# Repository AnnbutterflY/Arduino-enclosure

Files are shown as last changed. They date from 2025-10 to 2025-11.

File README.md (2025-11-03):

# 前言 Forward
本次课题是为Arduino设计外壳，制作要求为

This project involves designing a enclosure for Arduino, with the following requirements

**1、** 结合 3D 打印与激光切割技术

Combine 3D printing and laser cutting technologies

**2、** 禁止使用胶水，仅可使用螺丝或机械连接

The use of glue is prohibited; only screws or mechanical connections are allowed

**3、** 设计一个具有未来合理性的产品（Speculative Product），并为其制作外壳，推想该设计从构建一个可发生的未来开始。通过“未来世界”的设定，设计可以摆脱当下限制，探索替代思维

Design a speculative product with future plausibility and create a shell for it, imagining from the construction of a possible future. Through the setting of a "future world," design can break free from present constraints and explore alternative thinking

## 由此，我的世界构想为 Therefore, my world concept is:

**未来法律设定：** 所有家庭和公共空间不得使用一次性电子产品，所有硬件设备必须采用“可生长、可修复”的模块化设计，通过环境引导其功能发展。人们像培育植物一样“养”设备，而非简单购买固定功能的产品.

**社会形态与关键事件：** 地球经历工业体系崩塌和环境严重破坏的关键事件后，人类社会转向技术与生态共生的模式。社区不再依赖大型工厂生产日常设备，而是以家庭和社区为单位，通过“培养”技术植物满足生产和生活需求。社会形态呈现去中心化、生态化与模块化协作特征。

**整体环境与视觉风格：** 城市与废墟交融，建筑表面、屋顶、墙面遍布发光的电子藤蔓和生长的设备花朵。视觉风格融合科技与有机生物形态，光线柔和、呼吸式光源贯穿环境，半废墟、半生机的未来景观。

**生活方式、日常行为与核心需求:** 人们的生活不再围绕购买设备，而是通过培育和引导设备成长来满足生活需求。日常行为像照顾植物一样：调节光照、湿度和养分，引导设备长出不同功能模块。核心需求从“拥有设备”转向“培养、共生与管理设备成长”。

**Future Legal Framework:** All households and public spaces are prohibited from using disposable electronic products. All hardware devices must adopt a modular design that is “growable and repairable,” allowing their functions to develop through environmental guidance. People “nurture” devices like plants, rather than simply purchasing products with fixed functions.

**Societal Structure and Key Events:** Following critical events such as the collapse of industrial systems and severe environmental degradation, human society has shifted toward a model of technological-ecological symbiosis. Communities no longer rely on large factories to produce daily devices; instead, households and local communities “cultivate” technological plants to meet production and living needs. Society is characterized by decentralization, ecological integration, and modular collaboration.

**Overall Environment and Visual Style:** Cities blend with ruins, with building surfaces, rooftops, and walls covered in glowing electronic vines and blossoming devices. The visual style merges technology with organic, biological forms, featuring soft lighting and breathing light sources throughout the environment, creating a semi-ruined yet semi-vibrant futuristic landscape.

**Lifestyle, Daily Practices, and Core Needs:** Life is no longer centered on purchasing devices; instead, people nurture and guide devices’ growth to meet their needs. Daily actions resemble caring for plants: adjusting light, humidity, and nutrients to guide devices in growing different functional modules. Core needs have shifted from “owning devices” to “cultivating, coexisting with, and managing the growth of devices.”

# 反思 Reflection
在本次课题的制作过程中，我出现过问题。我制作的arduino外壳模型偏离了“HTAM”。

During the production process of this project, I encountered some problems. The Arduino case model I made deviated from the concept of “HTAM.”

我首先构思草图，然后用AI生图工具分别生成了华丽的底座与上半部分的成品2D图片。

I first sketched out my ideas, and then used an AI image-generation tool to create fantastic 2D images of an base and the upper part of the finished product.

<p align="center">
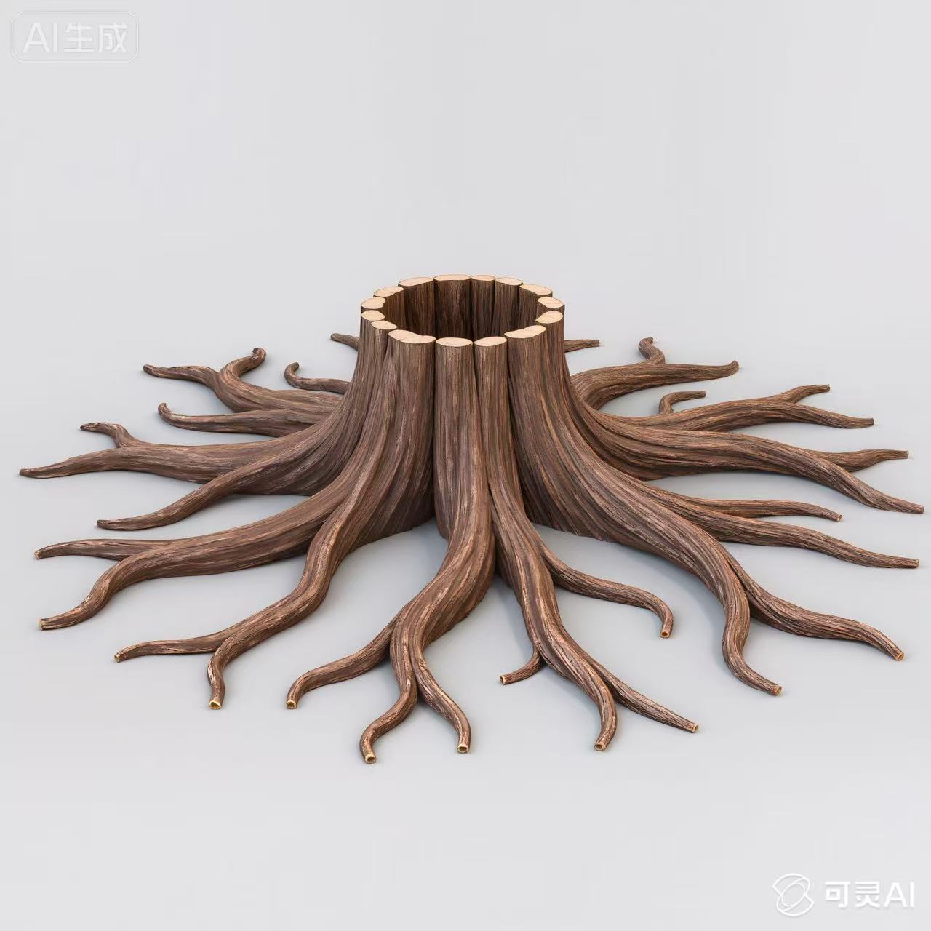
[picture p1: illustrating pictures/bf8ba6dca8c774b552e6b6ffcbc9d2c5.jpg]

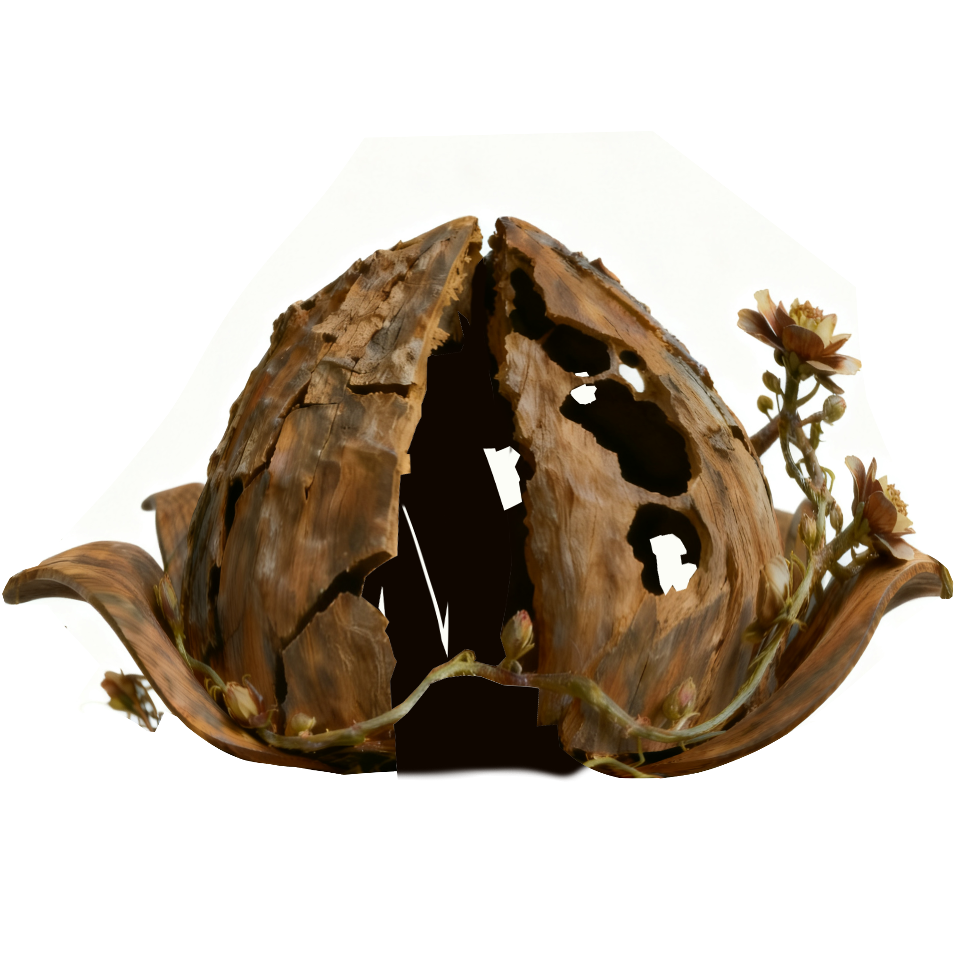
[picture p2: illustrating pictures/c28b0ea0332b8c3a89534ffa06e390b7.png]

</p>

接下来，我寻找到了AI生成模型网站：tripo3d（我的邀请码：E93EKF），我将图片上传，然后网站自动为我生成了模型。

Next, I found an AI model generation website called Tripo3D (my invitation code: E93EKF). I uploaded the images, and the site automatically generated 3D models for me.

<p align="center">
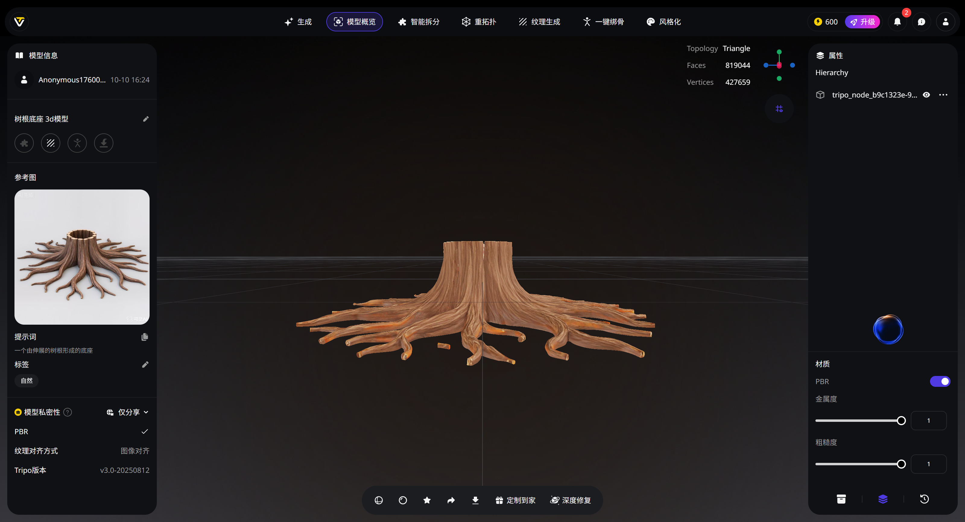
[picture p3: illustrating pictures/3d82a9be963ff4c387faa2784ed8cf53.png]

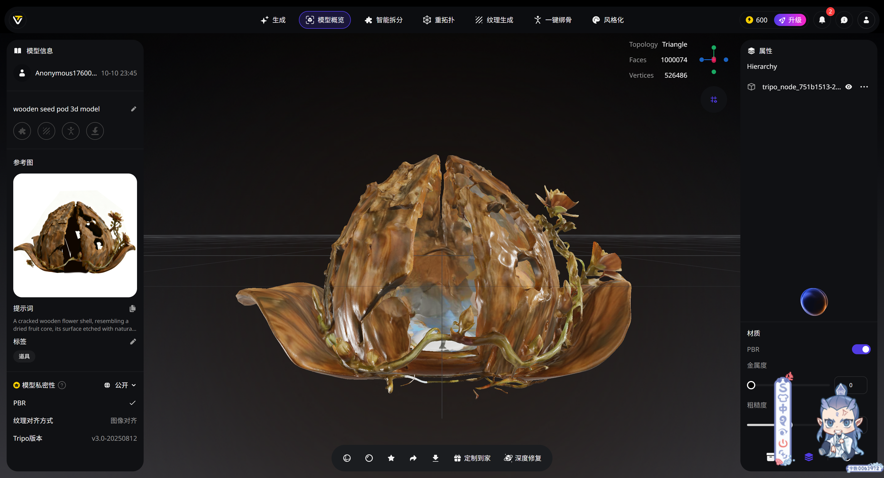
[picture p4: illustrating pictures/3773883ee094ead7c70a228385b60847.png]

</p>

于是，我将模型进行比例的修改，并进行破面修补、模型删减，并将底座与果壳结合在一起。

Then, I adjusted the proportions of the model, repaired broken surfaces, removed unnecessary parts, and combined the base with the shell.

最终，形成了一个类似火龙果的我的作品。

Eventually, my work took on the form of something resembling a dragon fruit.

<p align="center">
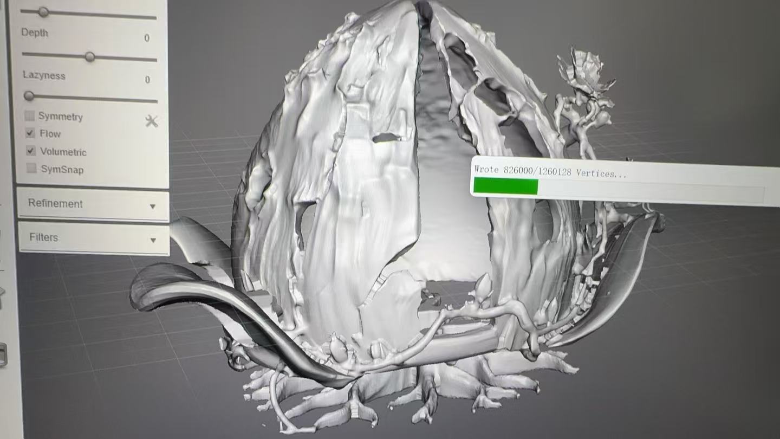
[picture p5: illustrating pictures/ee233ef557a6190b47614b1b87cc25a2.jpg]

</p>

然而，当我进入Fablab制作时，这一作品甚至难以被3D打印文件准备程序所预览，有无数需要支撑的部分，完全无法被制作、被生产。并且，我思考的将arduino放置于果壳内部的方式也不妥。更重要的是，这些设计完全没有必要。

However, when I brought the model to the Fablab for fabrication, it could barely even be previewed by the 3D printing preparation software—there were countless unsupported parts, making it completely impossible to produce.Furthermore, the way I planned to place the Arduino inside the shell was impractical. More importantly, these design decisions were entirely unnecessary.

<p align="center">
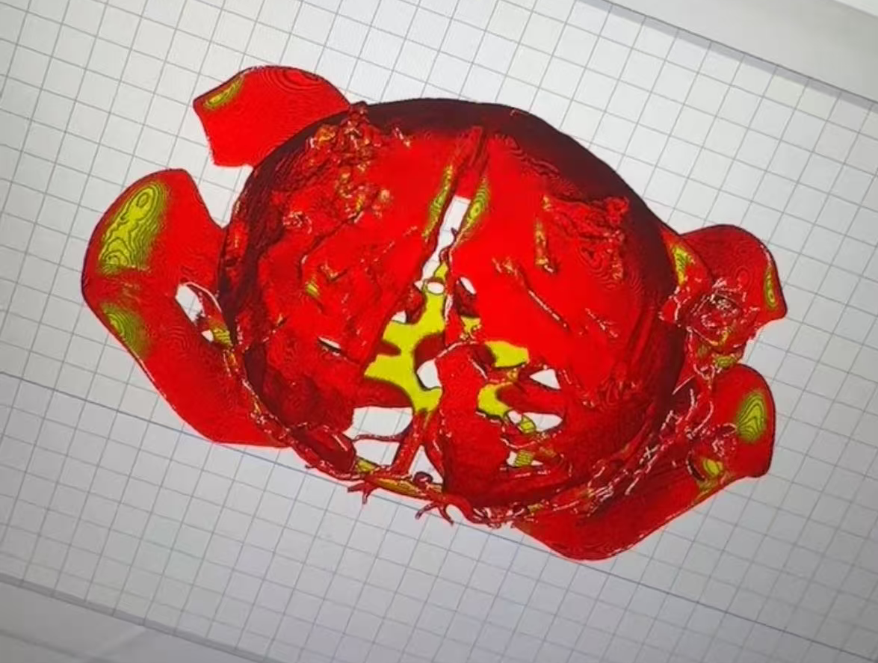
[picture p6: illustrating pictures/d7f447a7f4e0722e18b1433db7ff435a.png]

</p>

在这一过程中，我将它肆意捏造形状，而非关注于物体被激光切割和3D打印的制造方式，这导致我的外壳更像一个难以被制作的个人艺术装置，而不是未来的世界中的arduino外壳制作，完全脱离了制作目的。老师及时地提醒了我。在审课题时，我应该认真关注题目后的学会制造物品的意义。

Throughout this process, I focused on arbitrarily shaping forms rather than considering how the object would actually be made through laser cutting or 3D printing. As a result, my case looked more like a personal art installation that was nearly impossible to fabricate, rather than a practical Arduino case design for a futuristic world—it completely deviated from the purpose of making.Fortunately, my instructor reminded me in time. When reviewing the project, I realized I should focus more seriously on the meaning of learning to manufacture objects.

在经历这个过程后，我将模型重新拆分为上、下部分，将连接方式从不靠谱的打印件的捏造改为了结构穿插，并且修改了底座与外壳的形状，让他更符合未来arduino外壳的设计概念与我的未来世界规则，让他可被制造。

After going through this process, I split the model back into upper and lower parts, changed the unreliable printed connections into interlocking structural ones, and modified the base and shell shapes to better fit the design concept of a futuristic Arduino case and my envisioned world—making it manufacturable.

<p align="center">
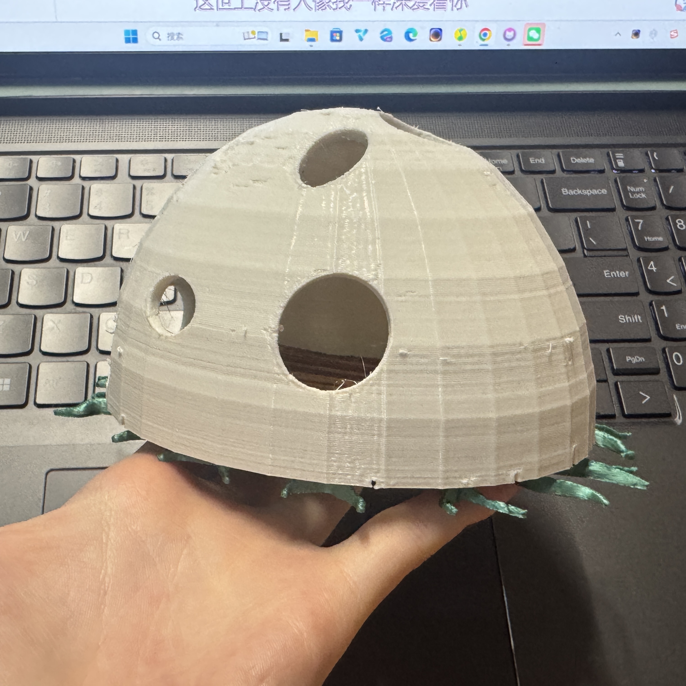
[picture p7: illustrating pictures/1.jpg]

</p>
<p align="center">  
改后制作完毕的样子
</p>  
<p align="center">  
The appearance after the revised version was completed.
</p>  

# tips:
我的教程中将会仅呈现如何制作出这样一个成品arduino外壳的完整过程，撇去了设计失败并迭代的过程。

In my tutorial, I will only present the complete process of how to make such a finished Arduino case, omitting the failed design attempts and iterations.

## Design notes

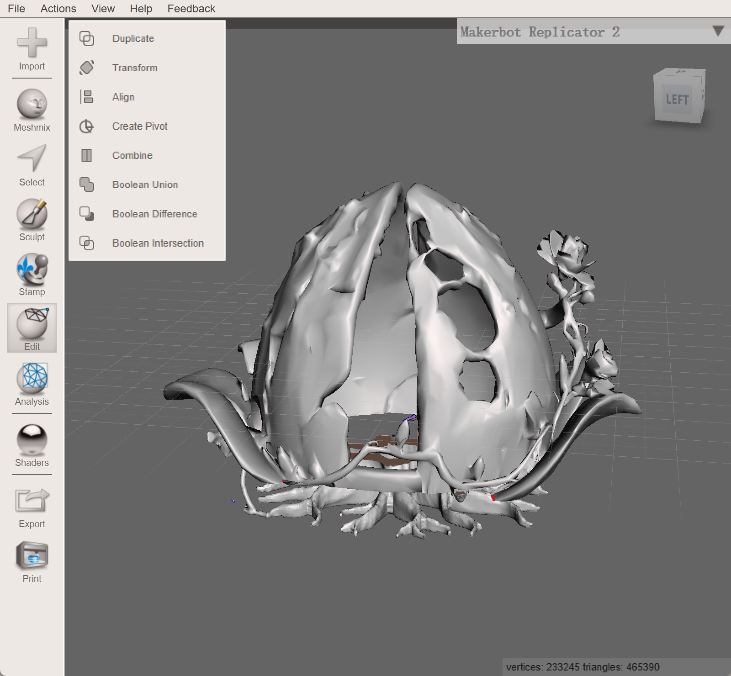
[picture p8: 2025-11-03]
illustrating pictures/e650ba2c14099867cfa3b52b1376ceb4.png

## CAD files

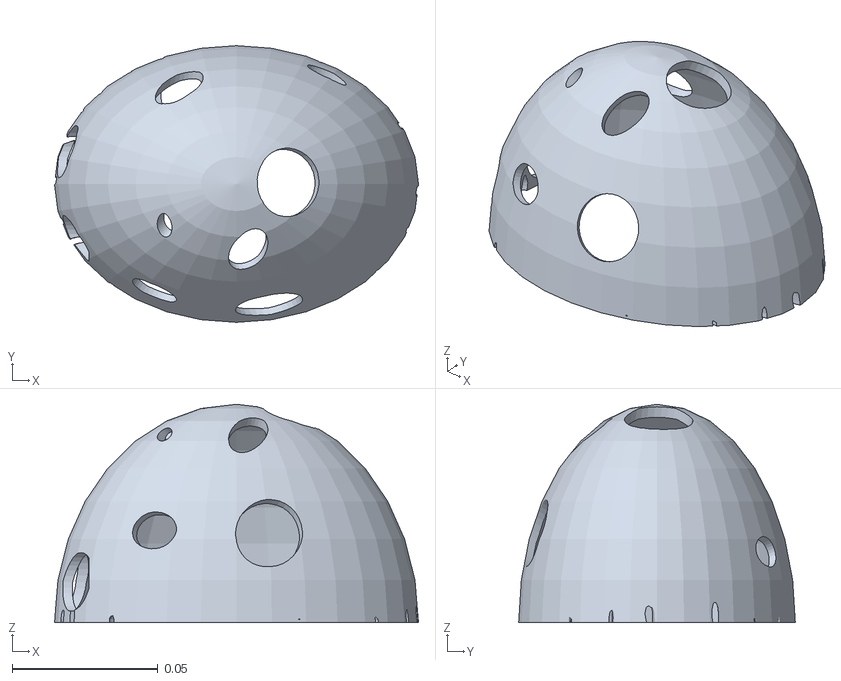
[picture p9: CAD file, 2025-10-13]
files/Shell (upper part).stl
0.125 x 0.095 x 0.075

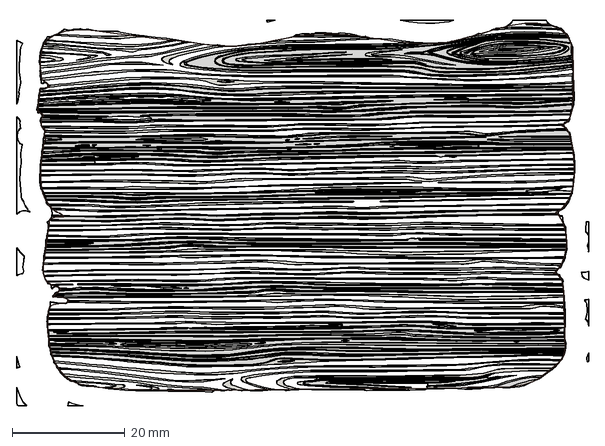
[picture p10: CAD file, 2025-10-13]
files/The wood board section for laser cutting.dxf
101.4 x 68.9 mm

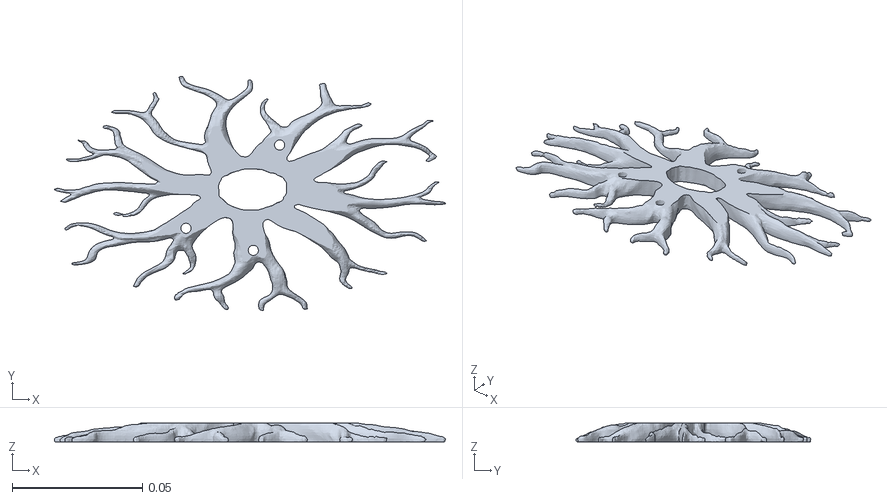
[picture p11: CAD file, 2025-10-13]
files/Base (lower part).stl
0.15 x 0.09 x 0.00716

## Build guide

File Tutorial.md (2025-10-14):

# 构思 Thinking  
在我的世界中，Arduino可根据周围环境的变化而**生长**，所以我名为**NURTSHELL**的外壳必须通透，留有余空，底座也要与环境共生，让Arduino被摆放在各个生长点上。  
In my envisioned world, the Arduino can **grow according to changes in its surroundings.** Therefore, my **NURTSHELL** must be transparent and spacious, and the base must coexist with the environment, allowing the Arduino to be placed at various growth points. I planned to use 3D printing to create a root-shaped base and a semi-enclosed shell, and laser cutting and engraving to build a wooden support inside.

# 木质支撑的制作 making the wooden support
## 第一步：制图  drawing
### 使用工具：AI  
**1、** 在官网（https://www.arduino.cc/ ）了解Arduino Uno R3的尺寸。  

Visit the official website (https://www.arduino.cc/) to learn the dimensions of the Arduino Uno R3.  
<p align="center">
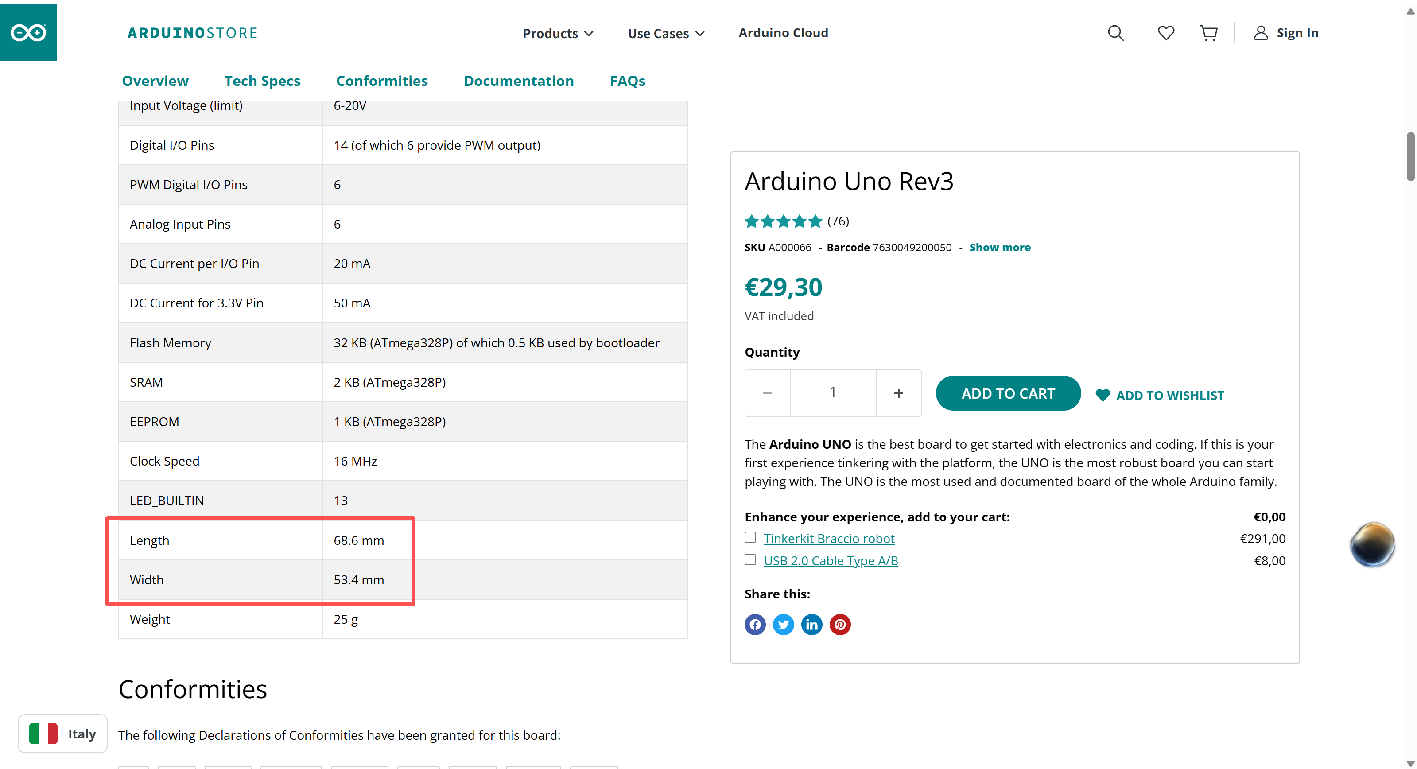
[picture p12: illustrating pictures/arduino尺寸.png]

</p>

**2、** 在AI中画出想要的木质支撑的切割形状，确保其能覆盖Arduino的大小。  

Draw the cutting shape of the wooden support in Illustrator (AI), ensuring it can cover the size of the Arduino.

**3、** 添加想要雕刻的纹路。  

Add the engraving patterns you desire.

<p align="center">
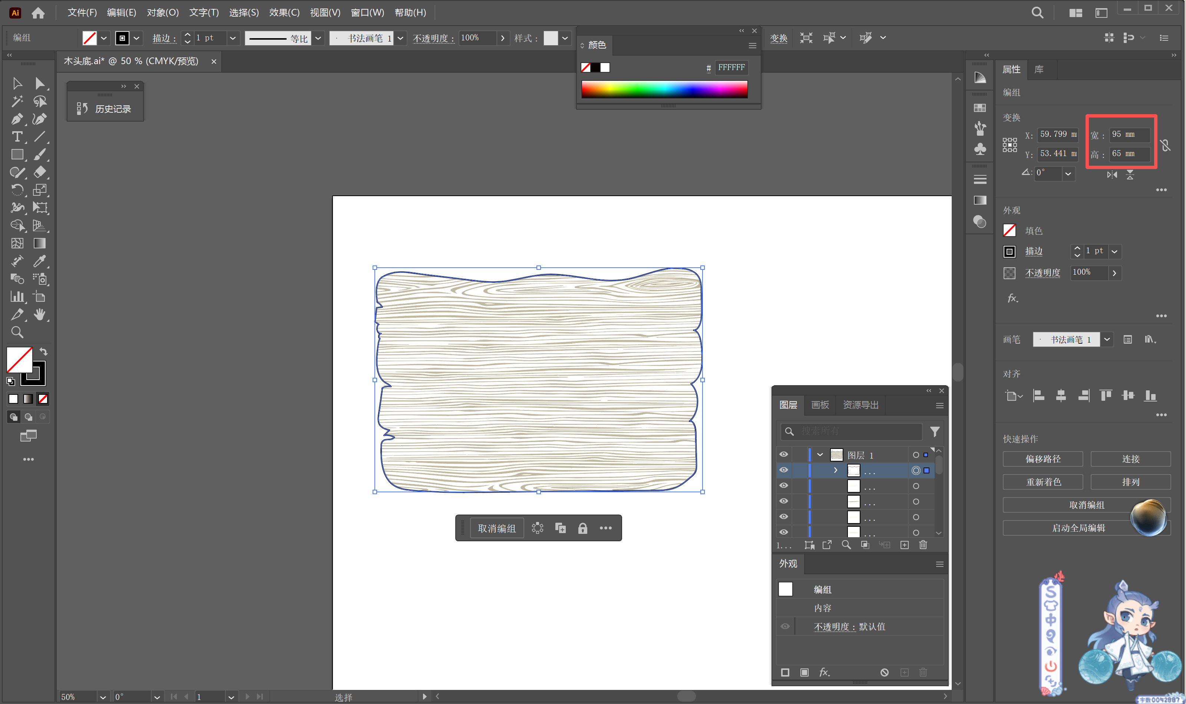
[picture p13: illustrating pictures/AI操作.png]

</p>
<p align="center">
我此处添加的雕刻纹路有些过于密集，打出来效果还可以，但尽量避免这么密集的线条。  
  
The engraving lines I added here were a bit too dense. Although the outcome was acceptable, it’s better to avoid such dense lines.
</p>

**4、** 留出需要与3D打印部分使用钉子连接固定的孔位。（我将使用直径为3.9mm的洞与其适配的热熔螺母、钉子）

**注意：** 此条需要重视，我就遗漏了这一步。 

Reserve holes for connecting with 3D-printed parts using screws. (I used 3.9 mm holes with matching heat-set inserts and screws.)  
 
**Note:** This step is crucial—I personally forgot it.

**5、** 将文件保存为**AI** 格式或**DXF**格式。  
 
 Save the file in **AI** or **DXF**format.

## 第二步：切割与雕刻  Cutting and Carving
### 使用工具：工坊一楼的激光切割机与一旁的电脑 The laser cutting machine on the first floor of the workshop and the computer next to it.

### 第一部分：电脑操作  
**1、** 在电脑上打开自己画好的图纸，打开方式选择LaserCAD。  

Open your design file on the computer using LaserCAD.

<p align="center">
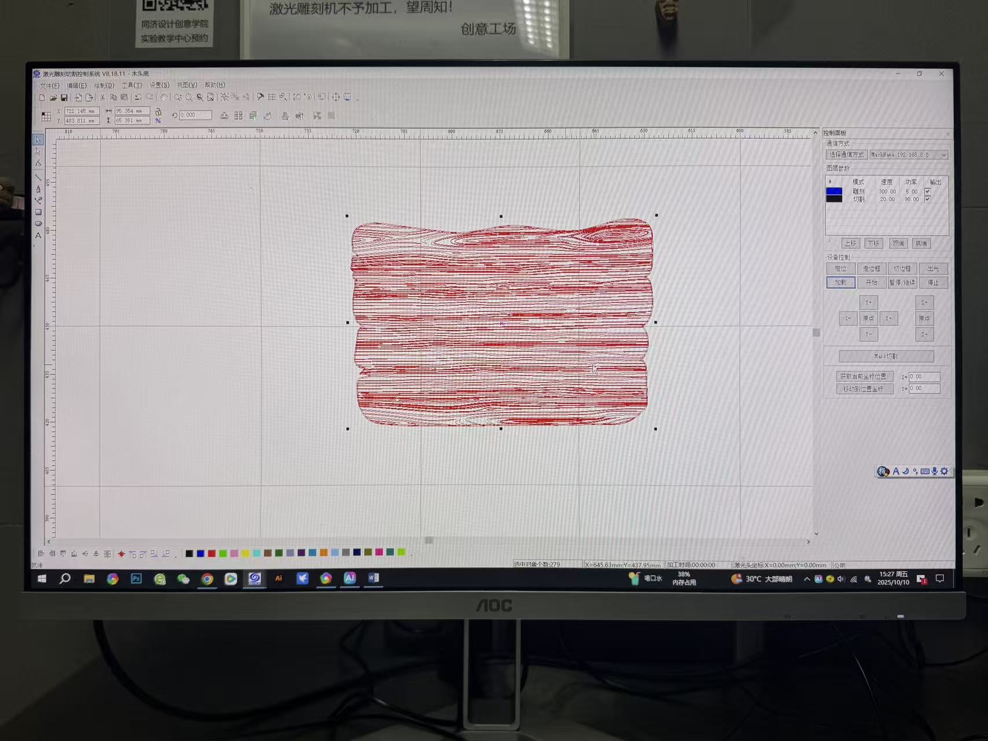
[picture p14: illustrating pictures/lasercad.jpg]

</p>

**2、** 观察图纸是否有乱线、图案是否完全显示。 

**提示：** 乱线删除即可，图案不显示很有可能是没有将文字、图形进行扩展。  

Check for stray lines or missing graphics.  

**Tip:** Delete stray lines; missing graphics are often caused by unexpanded text or shapes.

**3、** 全部选中线条，改为蓝色，需要切割的部分改为黑色。（剩下的蓝色部分为雕刻）  

原理：**不同颜色对应不同运行速度与功率，图层顺序先雕刻再切割。**  

Select all lines and set engraving lines to blue, cutting lines to black.  

Principle: **Different colors correspond to different speed and power settings. The machine engraves first, then cuts.**

<p align="center">
loading
</p>

**4、** 双击查看**右侧运行数值**，切割参数可参考电脑桌面“切割参数”PDF文件，雕刻参数可询问负责老师，3mm木板一般使用功率3-5，速度300。  

Double-click to view the **operation settings** on the right. Cutting parameters can be found in the “Cutting Parameters” PDF on the desktop; engraving parameters can be confirmed with the instructor. For 3mm wood, power 3–5 and speed 300 are typical.

<p align="center">
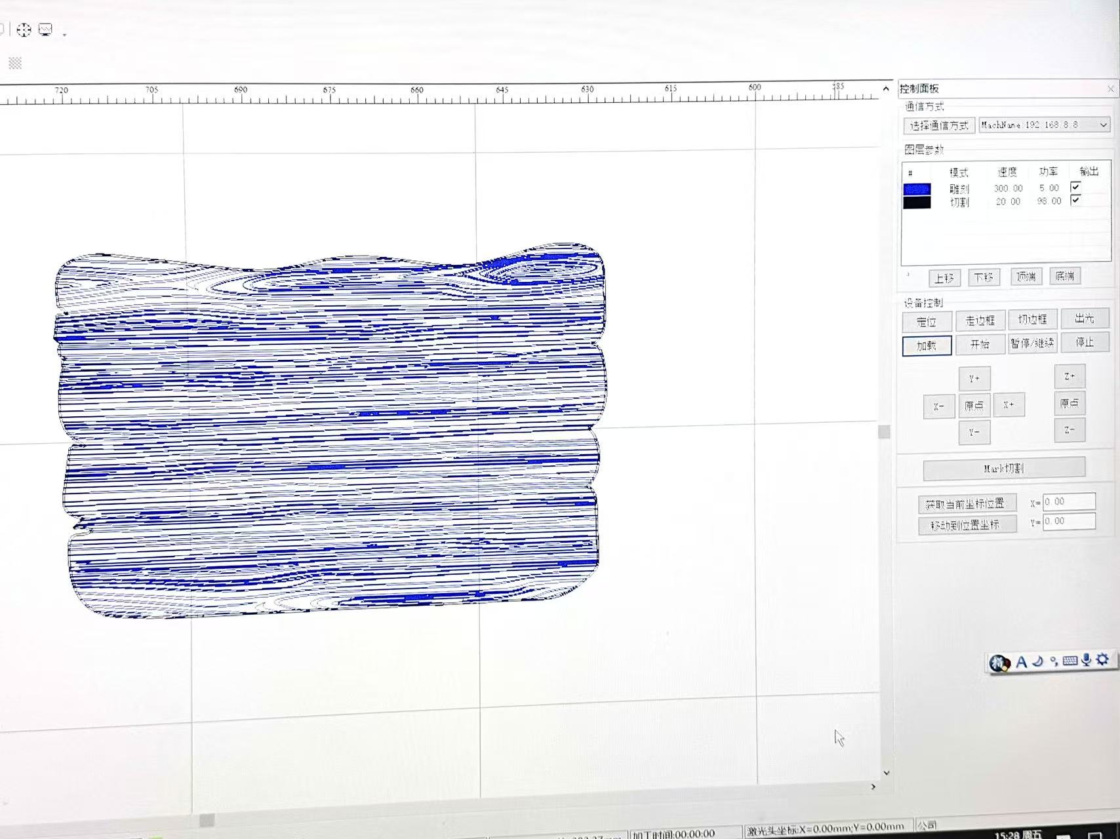
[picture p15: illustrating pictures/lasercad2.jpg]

</p>
<p align="center">
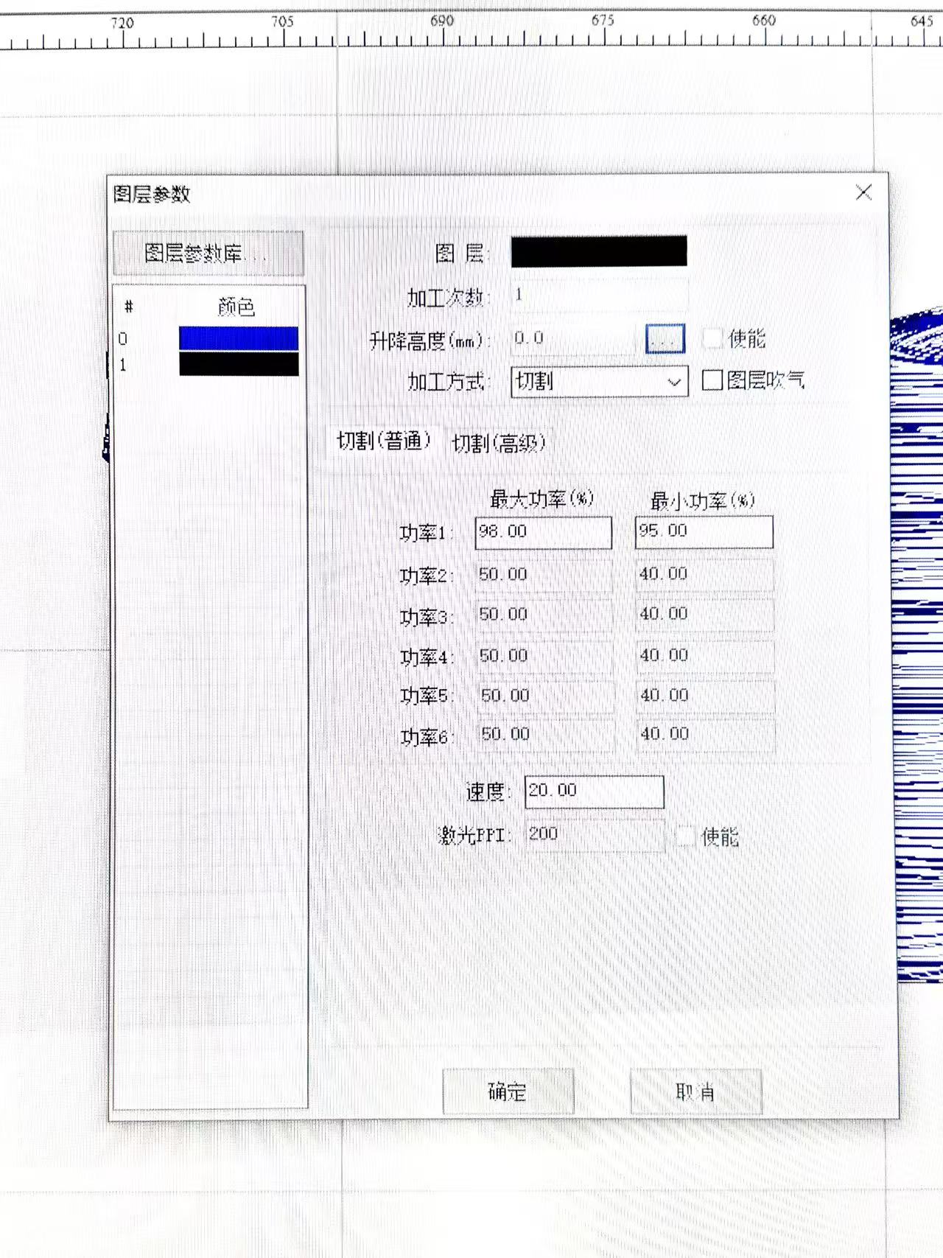
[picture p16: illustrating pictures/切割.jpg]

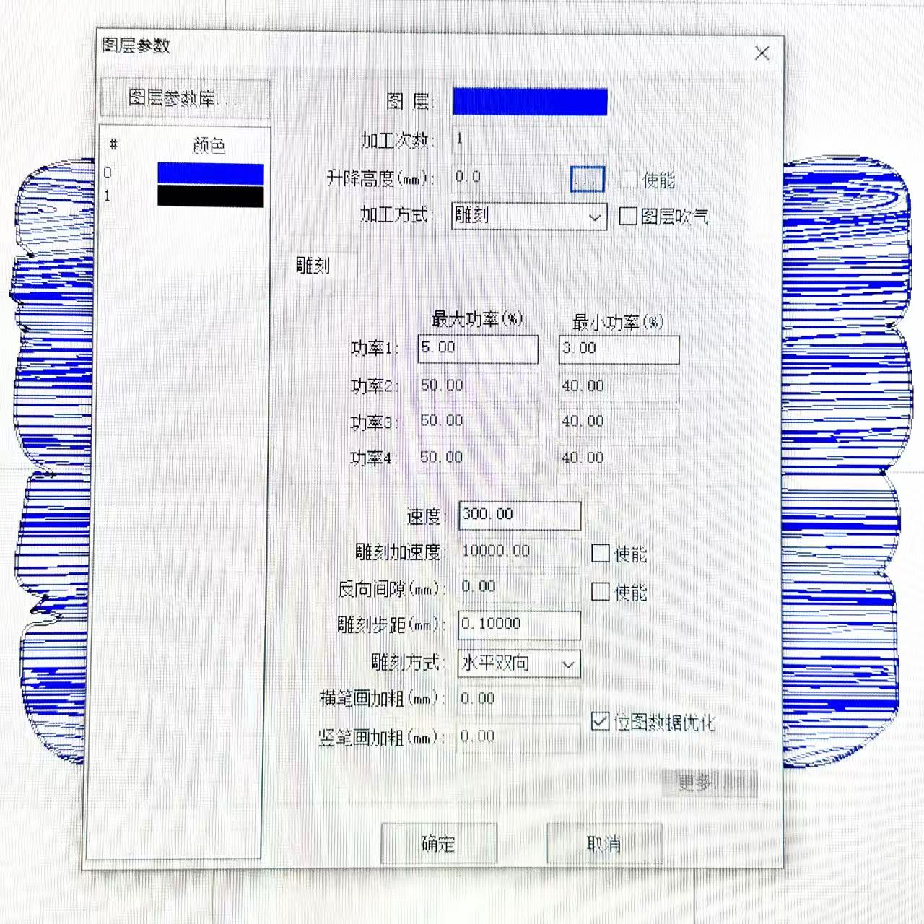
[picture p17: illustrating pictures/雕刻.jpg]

</p>

**5、** 全部选中进行加载。  
 
 Select everything and load it into the machine.

### 第二部分：激光切割机操作 Laser cutting
**1、** 旋转电源打开切割机，打开激光切割房门旁的**排风扇**。 

Turn on the power switch of the laser cutter and activate the **exhaust fan**
 next to the room door.

**2、** 图纸加载后，显示屏上应出现图案。打开舱门，将材料放在雕刻头附近，或使用按键操控雕刻头移向材料。  
**提示：舱门很重，请做好托举的准备再开合。**

After loading, the design should appear on the display. Open the chamber, place the material near the laser head, or move the head using the control buttons.  
**Tip: The chamber door is heavy—be prepared before opening or closing it.**

**3、** 点击**边框**按钮，走边框查看切割范围，检查是否被材料完全覆盖，确认后点击**定位**进行位置保存。  

Press the **Frame** button to preview the cutting boundary. Ensure the material fully covers the area, then press **Position** to save location.

**4、** 将机上U盘放入雕刻头与板材中间**测量焦距**，刚刚好即可，如需调节需要按动遥控板上的上、下按键。  

Use the onboard USB stick as a gauge between the laser head and the material to **set focal length**.Adjust using the up/down keys on the control panel if needed.

**5、** 关上舱门，点击**开始**，即开始切割。  

Close the chamber door and press **Start** to begin cutting.

<p align="center">
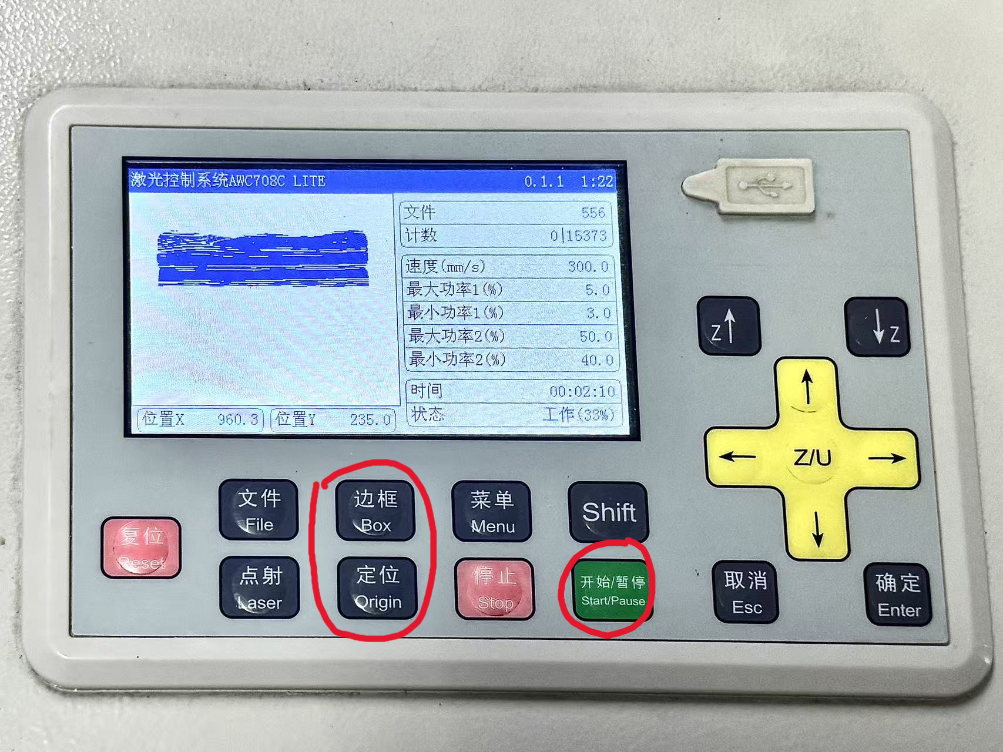
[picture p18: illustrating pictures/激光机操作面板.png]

</p>

<p align="center">
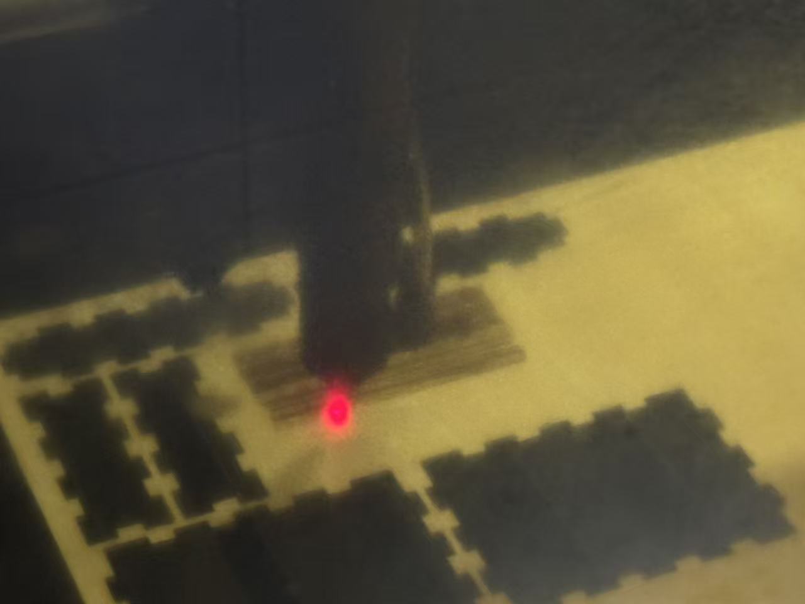
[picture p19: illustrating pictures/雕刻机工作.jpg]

</p>

**6、** 制作完毕后打开舱门，取下板材和成品，若成品掉入底部，需要拉开底部的抽屉进行拿取。  

 After processing, open the chamber, remove the material and finished part. If it falls inside, pull out the bottom tray to retrieve it.

<p align="center">
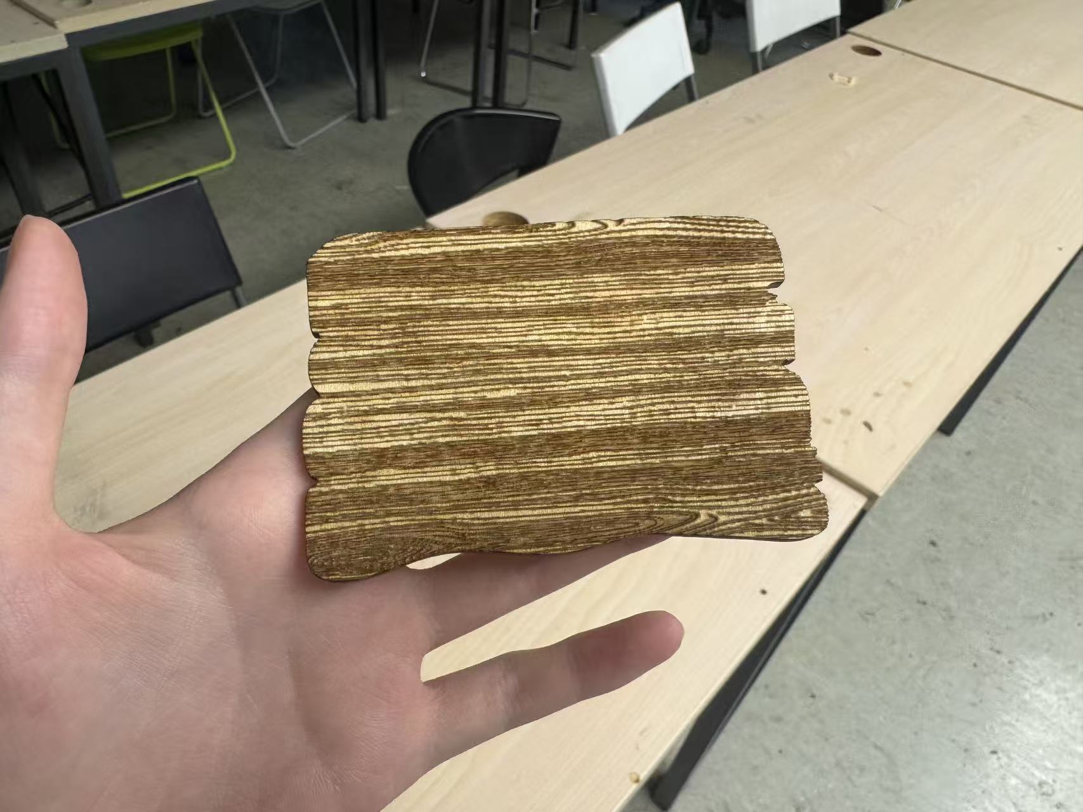
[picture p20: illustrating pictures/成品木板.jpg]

</p>

# 3D打印底座、壳子的制作 Making the 3D Printed Base and Shell

## 第一步：建模 Modeling

### 使用工具：Tripo3d、Blender、Meshmixer（可自行选择）  
### Tools Used: Tripo3d, Blender, Meshmixer (optional)

**1、** 根据尺寸精准地进行建模。  
 
 Model accurately according to the required dimensions.

<p align="center">
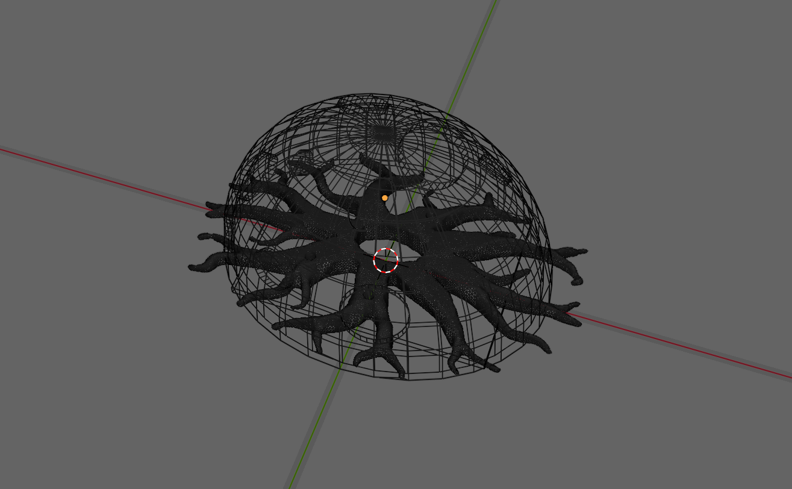
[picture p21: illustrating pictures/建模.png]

</p>

提示Tips：   
1、若使用Blender，导出时请注意**单位**的修改，否则导出的大小可能与建造时的比例不同。  

If using Blender, pay attention to adjusting the **units** when exporting, or the size may differ from the intended scale.  

2、留出需要安装热熔螺母的洞。（3D打印物件通常使用热熔螺母与螺丝钉来连接）  

Leave holes for inserting heat-set nuts. (3D printed parts usually use heat-set nuts and screws for assembly)

## 第二步：打印 Printing

### 使用工具：Ultimaker软件、Bambu Studio软件、对应打印机  
### Tools Used: Ultimaker Software, Bambu Studio, Corresponding 3D Printer

**1、** 将模型导入打印机对应的打印设置软件，进行大小检查、摆放、确定是否加支撑、设定内部结构的密度等。  

Import the model into the printer's slicing software, check size, positioning, decide whether supports are needed, and set infill density.

**2、** 进行 **Slice**查看，若发现不当之处回到第一步调整。  

Perform slicing and preview; if any issue is found, return to Step 1 to modify.

**3、** 保存打印文件，使用读卡器拷贝至储存卡。  

Save the print file and copy it to an SD card using a card reader.

**4、** 将储存卡插回打印机。打开打印机电源、进行预热、打印。  

Insert the SD card into the printer. Turn on the printer, preheat, and start printing.

<p align="center">
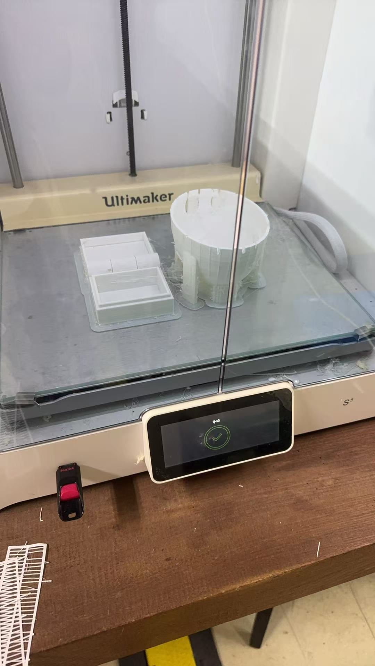
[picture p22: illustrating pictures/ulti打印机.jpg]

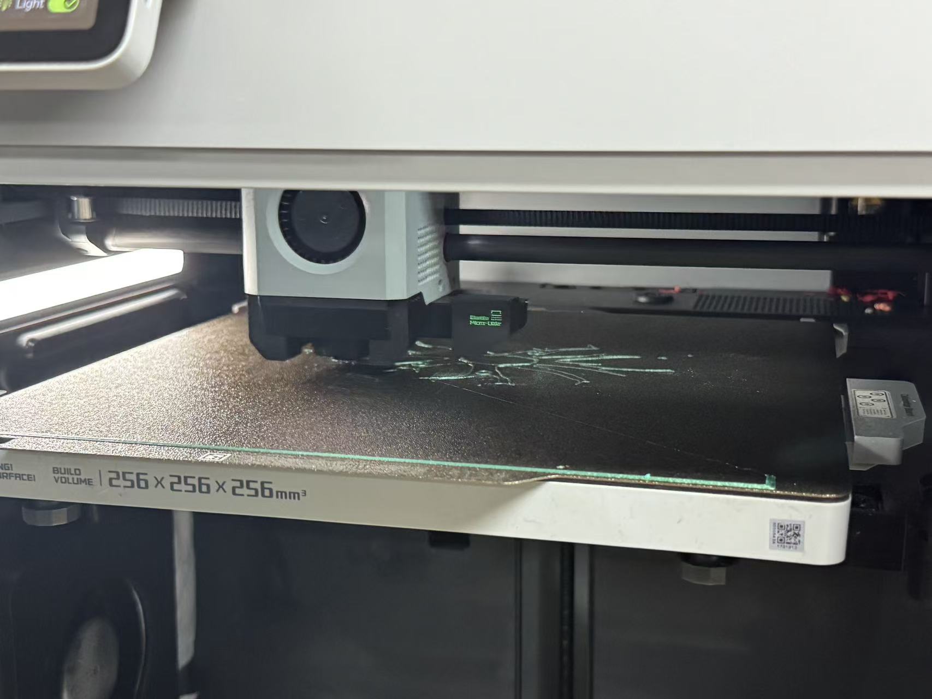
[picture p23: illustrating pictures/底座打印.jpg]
  
</p>

**5、** 打印完成后取出底板，待彻底 **冷却后铲下。**（不冷却完毕就铲除可能导致物品弯曲！）  

After printing, remove the base and only **scrape it off after it has completely cooled.**(Removing it too early may cause warping!)

**6、** 打理打印后的成品，如拆除支撑。  

Clean up the printed object, such as removing supports.

<p align="center">
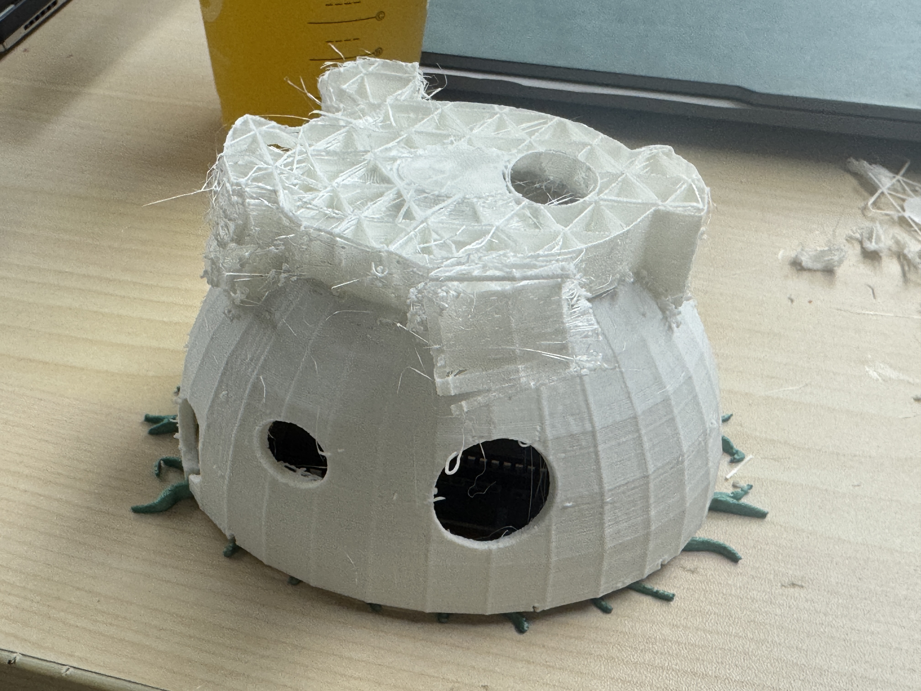
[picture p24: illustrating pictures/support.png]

</p>

<p align="center">  
这是支撑未完全拆掉时的样子  
  
This is how it looks before all supports are removed  
</p>

注意：  
Notes:  
1、使用工坊的自费打印机时，请务必向负责老师确认**Slice后的效果，** 以免出错后白做。  

When using self-funded workshop printers, always ask the instructor to confirm the **slicing preview** to avoid mistakes.  

2、使用Fablab中的Bambu打印机时，打印第一层时可以使用最低档速度，进行上层的打印时可以加快速度。  

When using Bambu printers in the FabLab, use the lowest speed for the first layer, and speed up for upper layers.

# 整体拼接 Final Assembly

**1、** 将大小合适的热熔螺母通过熔笔安装在打印件上。  

Install appropriate heat-set nuts into the printed parts using a soldering iron or heat pen.

<p align="center">
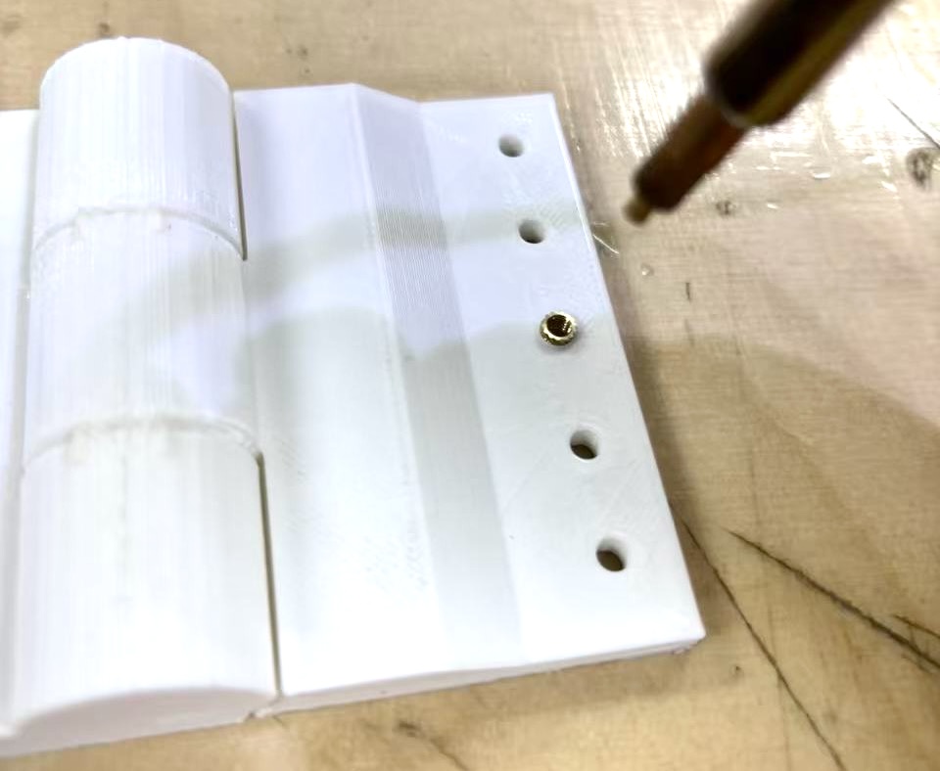
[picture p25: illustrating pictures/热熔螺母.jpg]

</p>
<p align="center">  
由于我忘记拍照，使用了同学相同步骤的照片  
</p>  
<p align="center">  
I forgot to take a photo, so I used my classmate’s photo for this step  
</p>  

**2、** 用螺丝刀将长度合适的螺丝钉安装木板与打印件。（打印件与打印件也如是安装）  

Use a screwdriver and screws of appropriate length to connect the wooden board and printed parts. (The same applies when connecting printed parts together)

<p align="center">
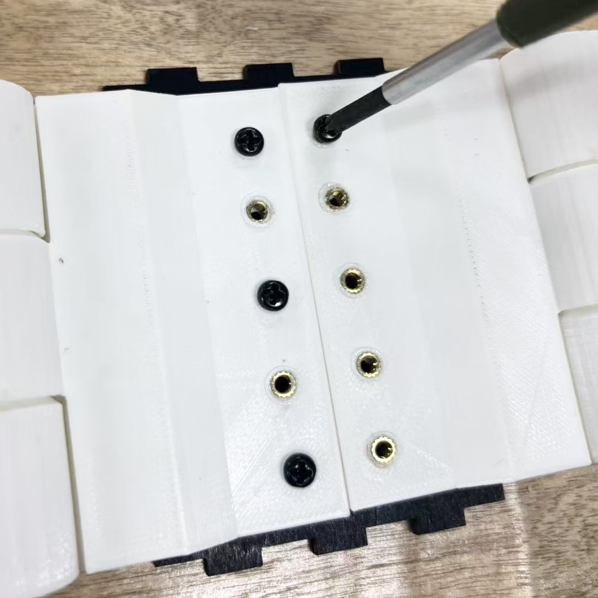
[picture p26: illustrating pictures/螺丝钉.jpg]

</p>

<p align="center">  
同样由于我忘记拍照，使用了同学相同步骤的照片  
</p>  
<p align="center">  
Again, I forgot to take photos, so I used my classmate’s  
</p>  

<p align="center"
>
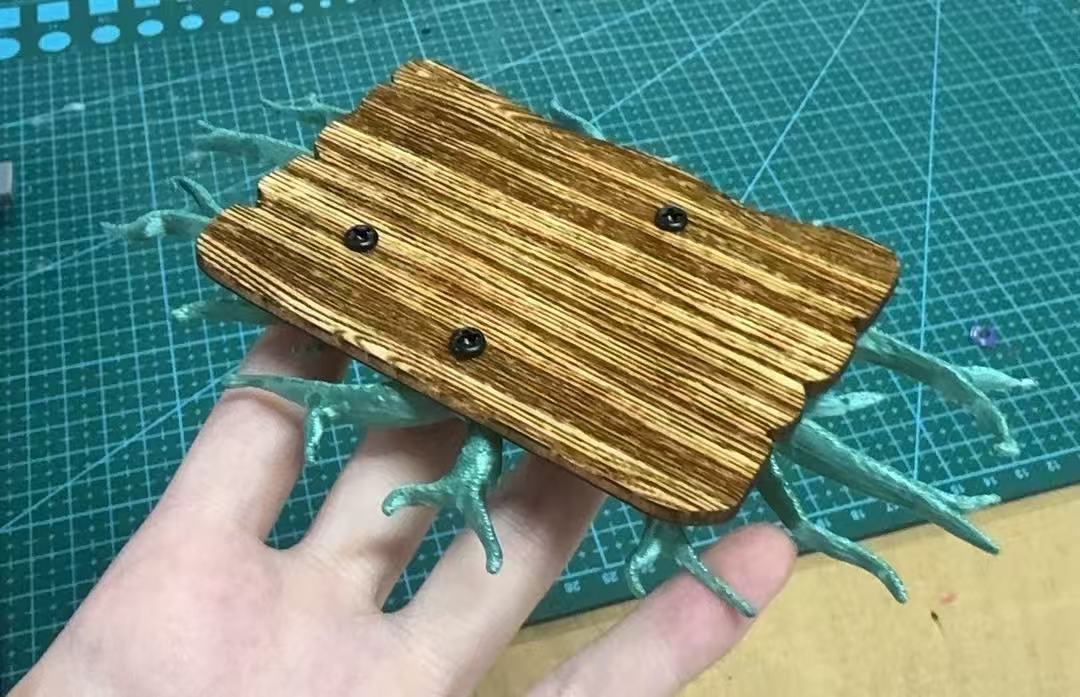
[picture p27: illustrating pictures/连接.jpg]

</p
>

<p align="center">  
我的打印底座与木板由此连接后的样子 
</p>
<p align="center">  
This is how my 3D printed base connects to the wooden board  
</p>

**3、** 整体组装！  

Final Assembly!

<p align="center"
>
loading
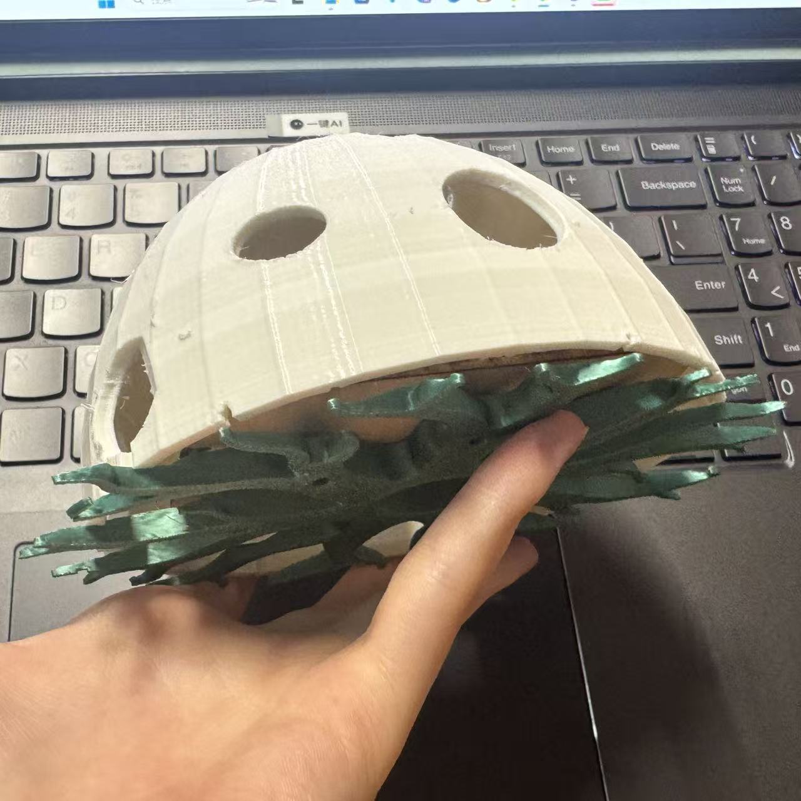
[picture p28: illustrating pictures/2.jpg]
  
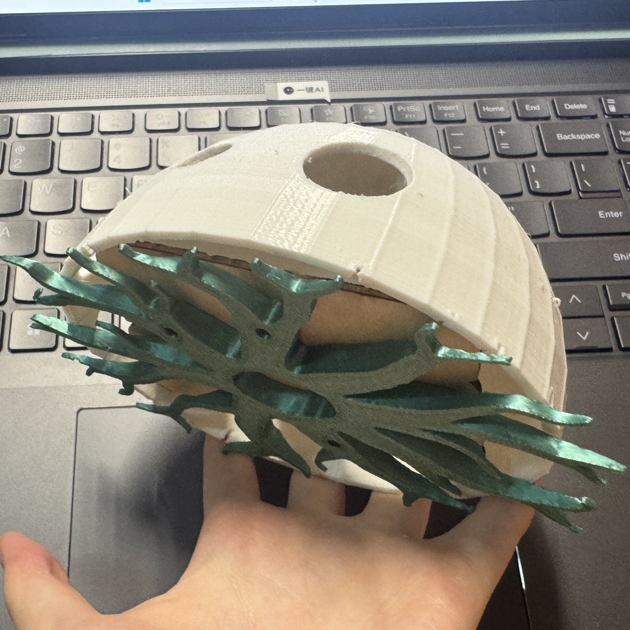
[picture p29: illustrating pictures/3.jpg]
  
</p
>
